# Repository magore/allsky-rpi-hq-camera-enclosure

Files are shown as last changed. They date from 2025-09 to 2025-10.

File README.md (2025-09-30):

# allsky-rpi-hq-camera-enclosure

## Copyright
[MIT License Copyright 2020-2025 Mike Gore]( Copyright.md )

## AllSky enclosure for Raspberry Pi and HQ Camera 
* Includes CAD models in Fusion 360<br>

* Supports Raspberry Pi 4 and 5 Models<br>

* Supports optional Ethernet with POE hats<br>

* Includes BME280 Weather Sensor with Temperature, Humidity and Air Pressure<br>
  + I hacked in the display of Weather sensor information. I just need to convert the code to the new module format and will share that once done.

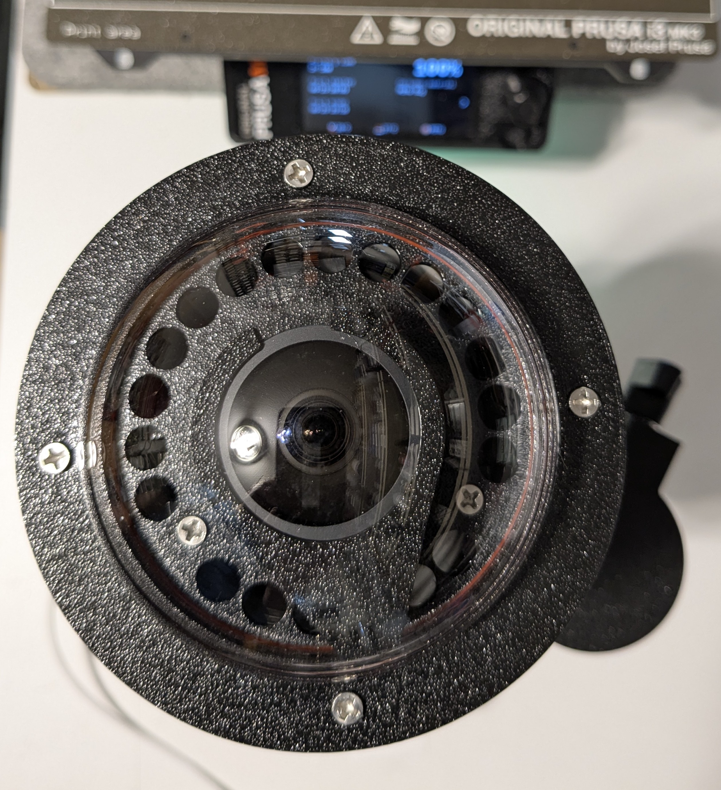
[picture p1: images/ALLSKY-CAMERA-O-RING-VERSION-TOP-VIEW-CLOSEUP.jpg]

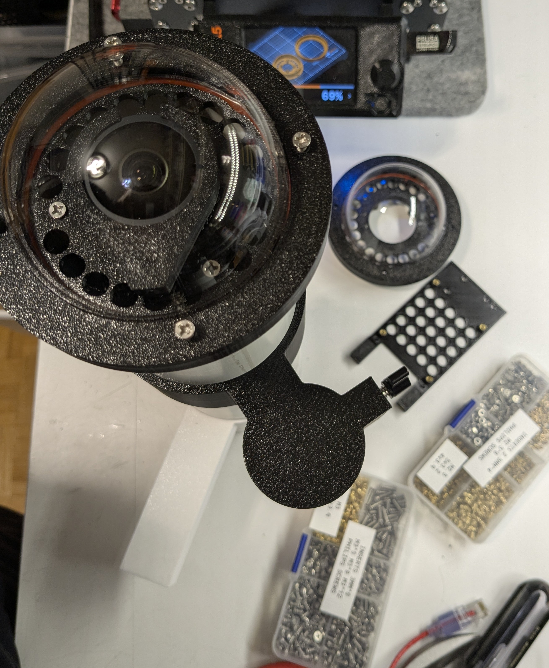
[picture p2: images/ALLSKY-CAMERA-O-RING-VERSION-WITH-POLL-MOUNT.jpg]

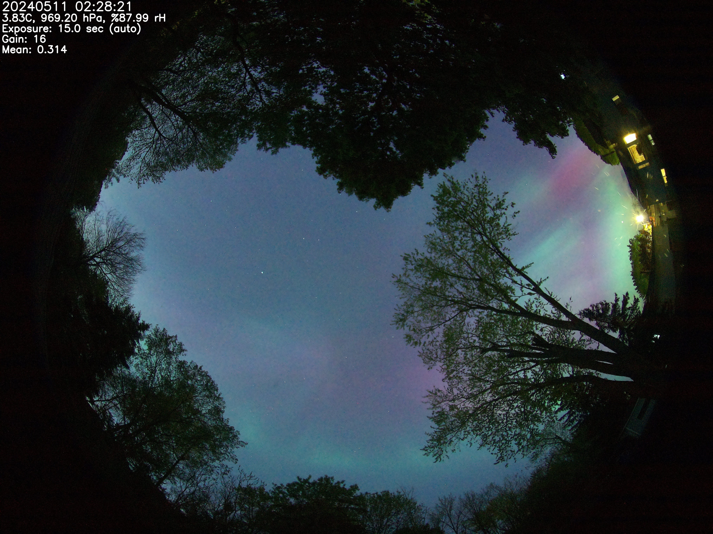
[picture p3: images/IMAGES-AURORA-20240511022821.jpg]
2024 Aurora Image

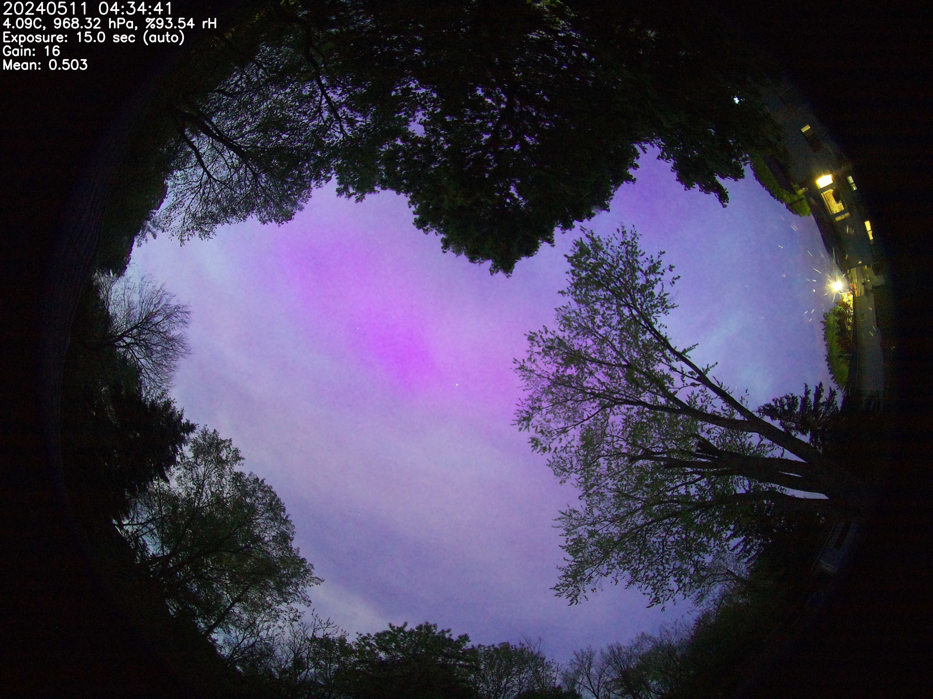
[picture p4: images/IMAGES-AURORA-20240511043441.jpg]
2024 Aurora Image

## Backround of this project
  * I started the ALLSKY Camera Enclosure project back in 2020 and have been using versions of it for the past several years
  * I created CAD models using Fusion 360 
  * I am now at the point where I feel comfortable with the design so I am completing documention presently

## Software requirement
https://github.com/AllskyTeam/allsky - this runs on the Raspberry PI<br>

## Hardware 

[Hardware Requirements]( HARDWARE.md )

[Assembly Instructions and Pictures]( ASSEMBLY.md )

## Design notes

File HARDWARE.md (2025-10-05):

## Hardware requirements
* Not all hardware listed is used - it depends on the Raspberry Pi version 4 or 5 and POE Hat used
* I used kits of stainless steel screws, brass hex spacers and JST connectors so specific part numbers for those items are not included. You can find them on Amazon

### Container, Cover and Weatherproofing
| Description | Source 1 | Source 2|
|---|---|---|
| 3.15inch/80mm w/ 4 Holes Clear Acrylic Flange Plastic | [LINK]( https://www.amazon.ca/dp/B07L6FBMXF ) | [LINK]( https://www.amazon.com/dp/B07L6FBMXF ) |
| IPEX Ecolotube 3 inch PVC Sewer Solid Sewer Pipe 76.2mm ID 82.5mm OD | SKU # 1000659635  [LINK]( https://www.homedepot.ca/product/ipex-ecolotube-3-inch-x-10-feet-pvc-sewer-solid-sewer-pipe/1000659635 ) | |
| 5 Gram Orange Indicatining Silica Packets | [LINK]( https://www.amazon.ca/dp/B07FSZVZFV ) | [ LINK]( https://www.amazon.ca/dp/B07FSZVZFV ) |
| PG7 Cable Gland  with gasket | | |
| Fusion Grip Tape - Silicone | [LINK]( https://www.amazon.ca/dp/B072QYQN7B ) | [LINK]( https://www.amazon.ca/dp/B072QYQN7B ) |
| Silicone O-Ring 82mm OD 76mm ID 3mm Width | [LINK]( https://www.amazon.ca/dp/B0DHRV93PH ) | [LINK]( https://www.amazon.com/dp/B0DHRV93PH ) |
| Silicone O-Ring 88mm OD 82mm ID 3mm Width | [LINK]( https://www.amazon.ca/dp/B0DHRRVRNT ) | [LINK]( https://www.amazon.ca/dp/B0DHRRVRNT) |
| Ethernet LAN Cable Coupler Outdoor Adapter Weatherproof Connection (6-Pack ) | [LINK]( https://www.amazon.ca/dp/B08GPB8M6B ) | [LINK]( https://www.amazon.com/dp/B08GPB8M6B ) |

### Camera and Lens Hardware
| Description | Source 1 | Source 2|
|---|---|---|
| Raspberry Pi HQ Camera Sony IMX477 | Digikey  2648-SC1220-ND | [LINK]( https://www.raspberrypi.com/products/raspberry-pi-high-quality-camera/ ) | 
| CS-MOUNT TO S-MOUNT ADAPTER | Digikey 2938-2000035953-ND | Basler Inc.  2000035953 |
| LOCK RING M12X0.5| Digikey 2938-2000035198-ND | Basler Inc. 2000035198 |
| 12MP 1.85MM ULTRA WIDE ANGEL | Digikey 4555-ED-LENS-M12-170185-12-ND | EDATEC ED-LENS-M12-170185-12 |

### Environmental Sensor and Cables
| Description | Source 1 | Source 2|
|---|---|---|
| QWIIC BME280 ATMOSPHERIC SENSOR | DigiKey 1568-15440-ND | SparkFun 15440 |
| Sparkfun Qwiic Multiport BOB-18012 | Digikey 1568-18012-ND | Sparkfun BOB-18012 | 
| SparkFun Qwiic Cable BOB-18012 | 1568-15081-ND | Sparkfun BOB-18012 | 
| SCREEN Cover - using Faucet Aerator Parts 15/16" | [LINK]( https://www.amazon.ca/dp/B08XNRCDV6 ) | [LINK]( https://www.amazon.com/dp/B08XNRCDV6 ) |

### Misc Connectors
| Description | Source 1 | Source 2|
|---|---|---|
| 2 x 20 (40 Pin) Extra Tall Female 0.1 Inch Pitch Stacking Header | [LINK]( https://www.amazon.ca/Female-Stacking-Header-Compatible-Raspberry/dp/B084Q4W1PW ) | [LINK]( https://www.amazon.com/Female-Stacking-Header-Compatible-Raspberry/dp/B084Q4W1PW ) |
| JST SM female connector Kit | [LINK]( https://www.amazon.ca/dp/B07BGV7H7V ) | [LINK]( https://www.amazon.com/dp/B07BGV7H7V ) |
| ( OPTIONAL ) Micro Molex Crimper: Compatible with D-Sub, JST, JAE Connectors, 32-20AWG | [LINK]( https://www.amazon.ca/dp/B082X45D7T ) | [LINK]( https://www.amazon.ca/dp/B082X45D7T ) |

### Focusing
| Description | Source 1 | Source 2|
|---|---|---|
| 5x10 mm cylinder Neodymium Magnet for focus pointer | [LINK]( https://www.amazon.ca/dp/B0DQKTHBCN ) | [LINK]( https://www.amazon.com/dp/B0DQKTHBCN ) |
| 12x12 mm cylinder Neodymium Magnet external focus magnet | [LINK]( https://www.amazon.ca/dp/B07BS5N22P ) | [LINK]( https://www.amazon.ca/dp/B07BS5N22P ) |

### Cooling
| Description | Source 1 | Source 2|
|---|---|---|
| Noctua NF-A4x10 5V 40x10mm PREMIUM FAN | [LINK]( https://noctua.at/en/products/fan/nf-a4x10-5v ) | |

### POE Networking
| Description | Source 1 | Source 2|
|---|---|---|
| Goalake Poe Managed 5 Port Gigabit Switch | [LINK]( https://www.amazon.ca/dp/B0D2X4M1R7 ) | [LINK]( https://www.amazon.com/dp/B0D2X4M1R7 ) |

### Raspberry PI 4 Specific

#### Raspberry PI 4 Camera
| Description | Source 1 | Source 2|
|---|---|---|
| Raspberry Pi 4 Camera Cable 200mm | | |

#### Raspberry Pi 4 POE
| Description | Source 1 | Source 2|
|---|---|---|
| Waveshare Raspberry Pi 4 POE HAT (E) | [LINK]( https://www.amazon.ca/dp/B0BKK6FXRJ ) | [LINK]( https://www.amazon.com/dp/B0BKK6FXRJ ) |

### Raspberry PI 5 Specific

#### Raspberry PI 5 Camera 
| Description | Source 1 | Source 2|
|---|---|---|
| Raspberry Pi 5 Shielded Camera Cable 200mm | [LINK]( https://www.raspberrypi.com/products/camera-cable/ ) | |

#### Raspberry PI 5 POE HAT OPTIONS
| Description | Source 1 | Source 2|
| Hacker Gadgets Raspberry Pi 5 POE+ Nvme Hat | [LINK]( https://hackergadgets.com/products/nvme-and-poe-hat-for-raspberry-pi-5 ) | |
| (untested ) Waveshare PCIe To M.2 Adapter With PoE Function (C ) For Raspberry Pi 5, Supports NVM | [LINK]( https://www.waveshare.com/poe-m.2-hat-plus-c.htm ) | |

#### Raspberry PI 5 NVME SSD
| Description | Source 1 | Source 2|
|---|---|---|
| Raspberry Pi 5 CORSAIR MP600 MINI 1TB M.2 NVMe PCIe x4 Gen4 2 SSD 2230 | [LINK]( https://www.amazon.ca/dp/B0D9MJCFNK ) | [LINK]( https://www.amazon.com/dp/B0D9MJCFNK ) |

### Screws and Inserts

| Description | Source 1 | Source 2|
|---|---|---|
| 1/4"-20 x 1 Black Thread Thumb Screw, Stainless Steel | [LINK]( https://www.amazon.ca/dp/B0DC5Y3KLQ ) | [LINK]( https://www.amazon.com/dp/B0DC5Y3KLQ ) |
| CNC Kitchen Heatset Inserts M3 H=5.7mm, W=4.6mm, 3.9mm sholder | [LINK]( https://cnckitchen.store/products/heat-set-insert-m3-x-5-7-100-pieces ) | |
| uxcell Knurled Insert Nuts Heatset Inserts M2.5 H=5mm, Wx4mm, 3.25mm sholder | [LINK]( https://www.amazon.ca/dp/B0CTCS2HLT ) | [LINK]( https://www.amazon.ca/dp/B0CTCS2HLT ) ] |
| M3 x 12 Phillips Flat Head Stainless Machine Screw | | |
| M3 x 20 Phillips Flat Head Stainless Machine Screw | | |
| M2.5 x 6 Phillips Flat Head stainless Machine Screw | | |
| M4 x 20 Philips Pan Head Stainless Machine Screw | | |
| M4 Nuts Stainless Machine Screw | | |
| M4 Nuts Stainless Washers | | |
| M2.5 x 6 Brass Standoffs Female-Female | | |
| M2.5 x 15 Brass Standoffs Female-Female | | |

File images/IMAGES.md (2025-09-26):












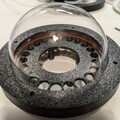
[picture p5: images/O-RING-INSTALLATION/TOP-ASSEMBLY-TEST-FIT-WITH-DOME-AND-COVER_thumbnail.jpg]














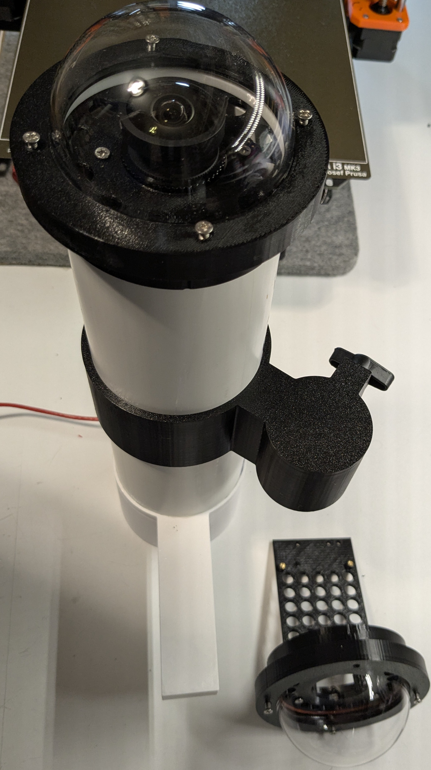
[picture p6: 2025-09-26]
images/OPTICAL-DONE-GASKET-VERSION/ALLSKY-CAMERA-WITH-GASKET-COVER-VERSION.jpg

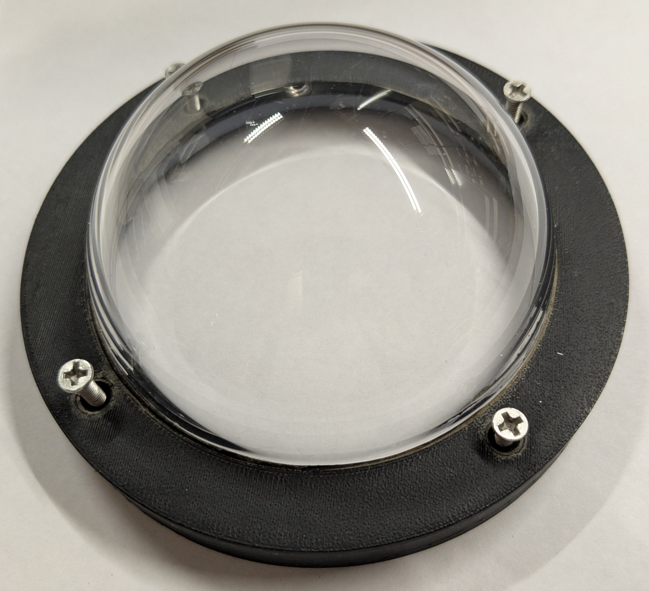
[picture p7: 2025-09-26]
images/OPTICAL-DONE-GASKET-VERSION/OPTICAL-DOME-COVER-GASKET-VERSION.jpg

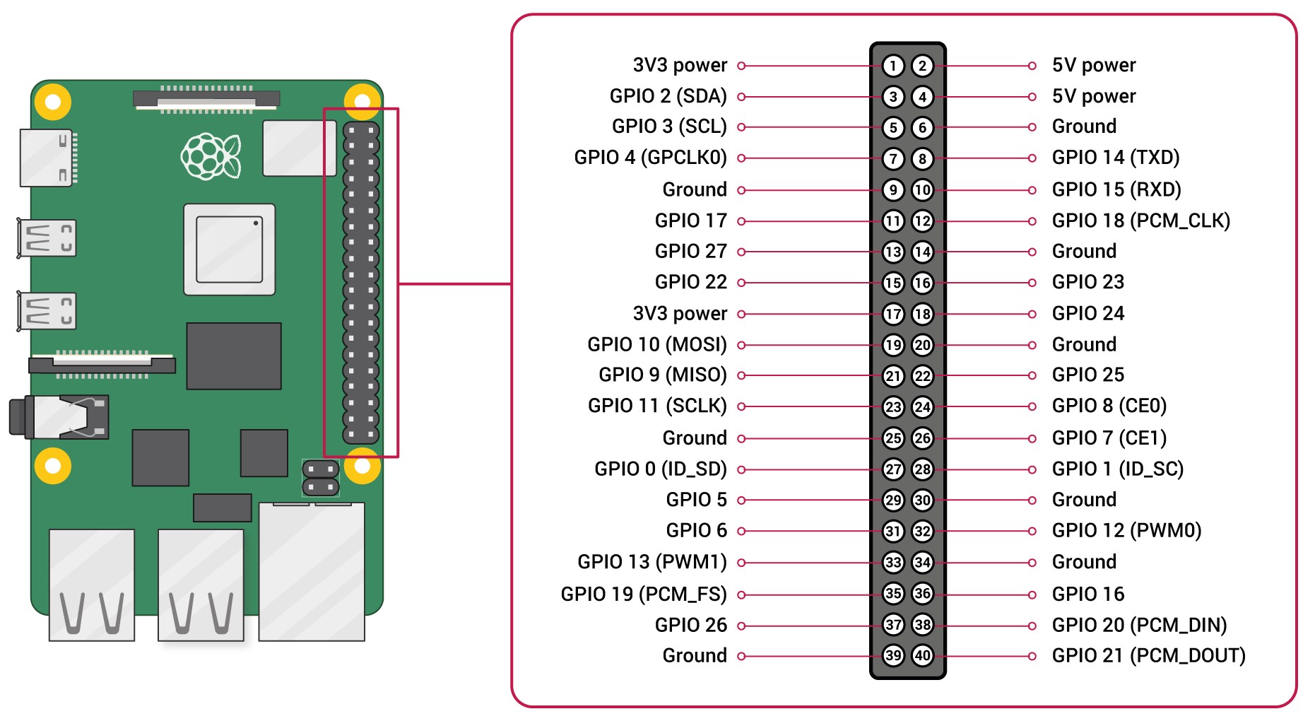
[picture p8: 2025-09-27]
images/RPI-INSTALLATION/RPI-GPIO-PINOUT.jpg

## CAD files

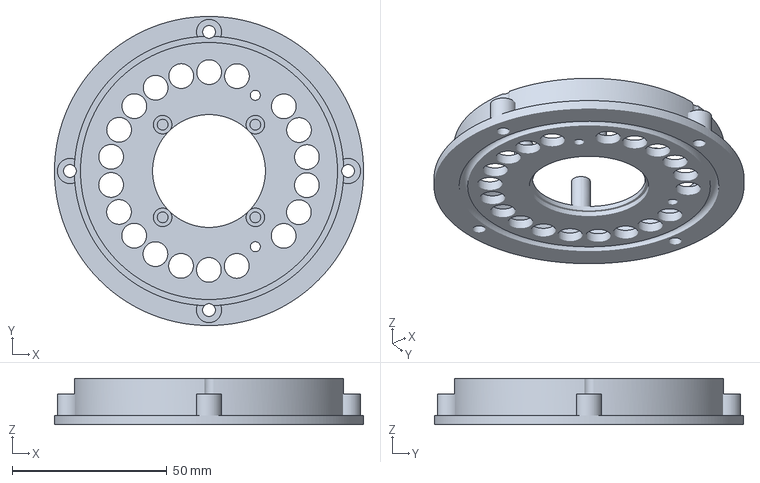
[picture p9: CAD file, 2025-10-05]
CAD/cap-main-o-ring.3mf
100.0 x 100.0 x 15.0 mm

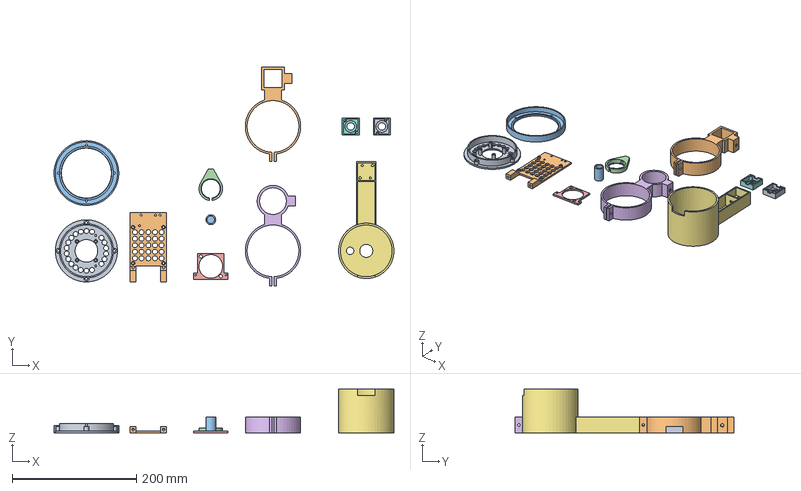
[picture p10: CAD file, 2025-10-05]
CAD/CAP-ORING v27.step
546.7 x 351.6 x 70.0 mm
cap-main-o-ring
cap-rpi-support
cap-dome-holder-o-ring
cap-focus-pointer
cap-fan-holder
cap-poll-holder
cap-weather-sheild
cap-weather-shield-cover-sparkfun-bme280
cap-weather-shield-cover-adafruit-bme680
cap-poll-holder-28x28-poll-2
cap-magnet-holder

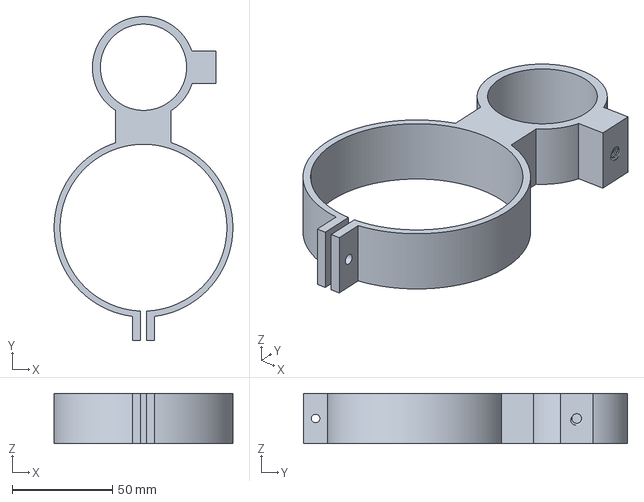
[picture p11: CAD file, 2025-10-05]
CAD/cap-poll-holder.3mf
89.1 x 161.6 x 25.0 mm

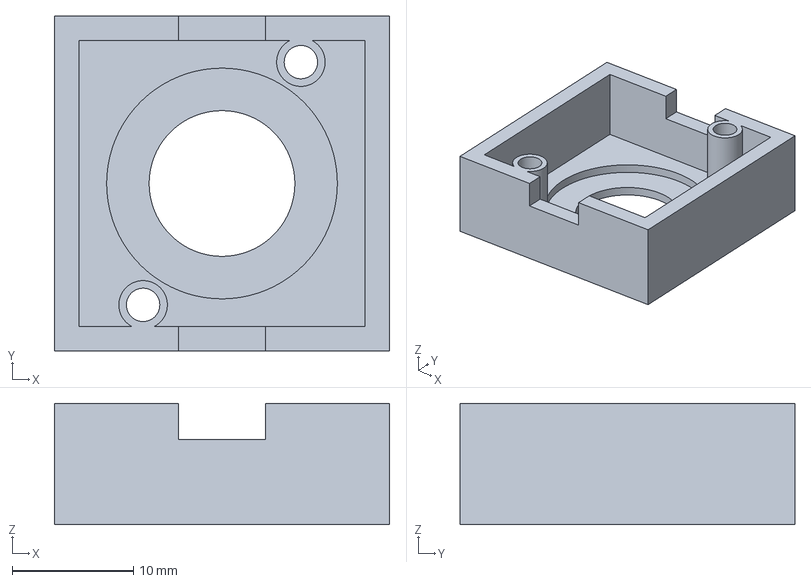
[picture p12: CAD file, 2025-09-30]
CAD/cap-weather-shield-cover-adafruit-bme680.3mf
27.6 x 27.6 x 10.0 mm

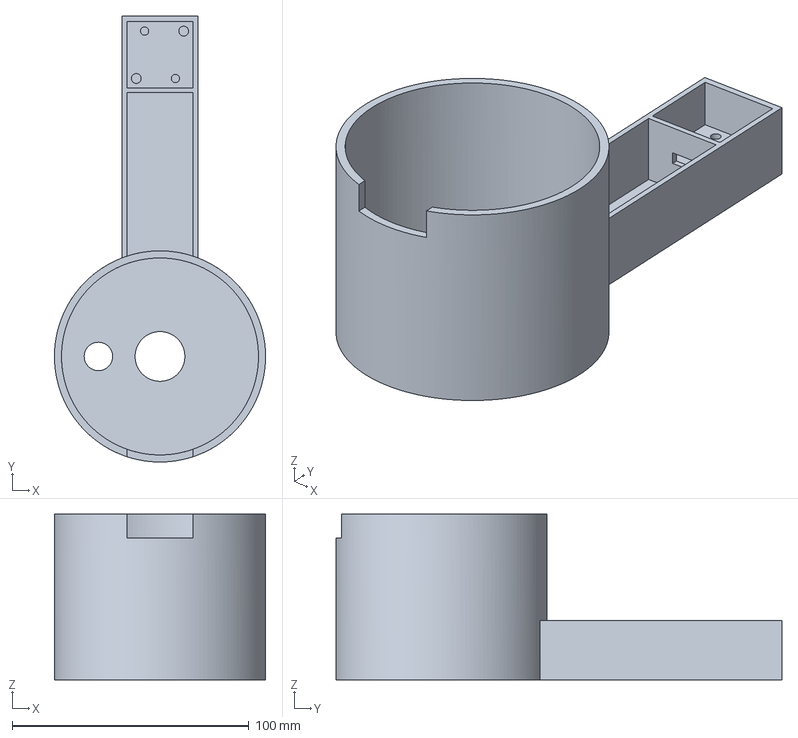
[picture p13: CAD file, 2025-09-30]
CAD/cap-weather-sheild.3mf
89.2 x 188.3 x 70.0 mm

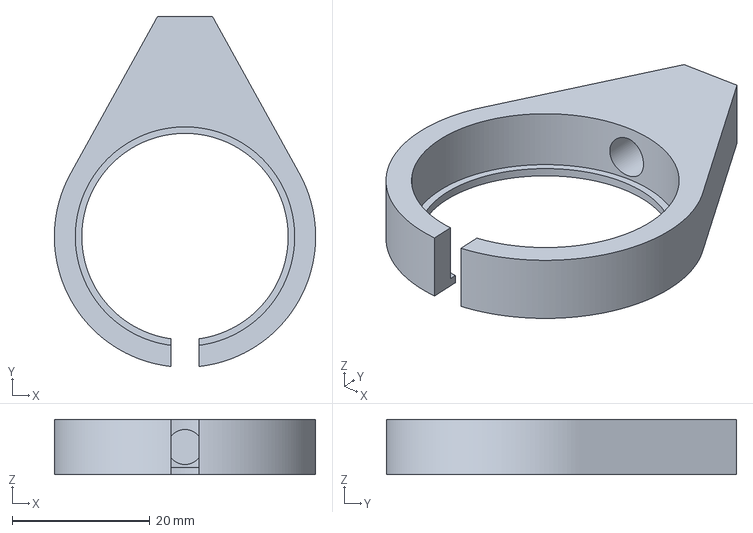
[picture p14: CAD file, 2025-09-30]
CAD/cap-focus-pointer.3mf
38.0 x 50.9 x 8.00 mm

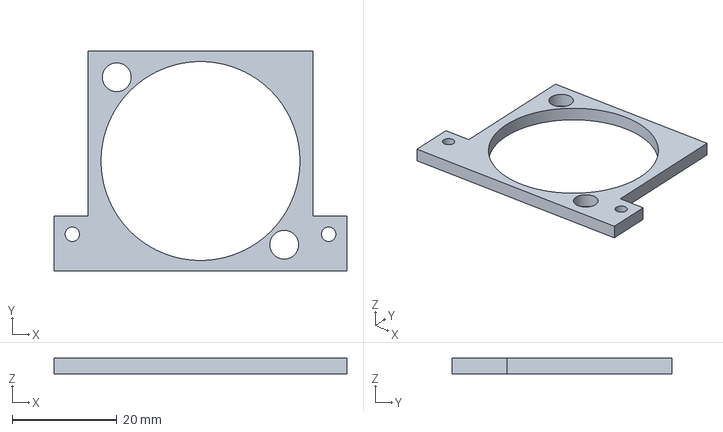
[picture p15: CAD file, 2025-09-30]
CAD/cap-fan-holder.3mf
56.0 x 42.0 x 3.00 mm

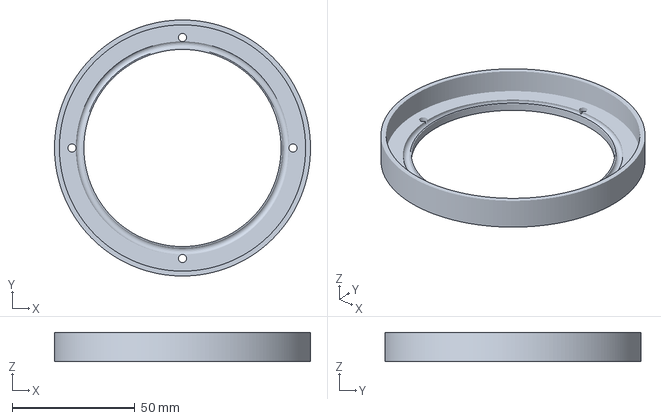
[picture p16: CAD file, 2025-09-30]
CAD/cap-dome-holder-o-ring.3mf
104.2 x 104.2 x 12.0 mm

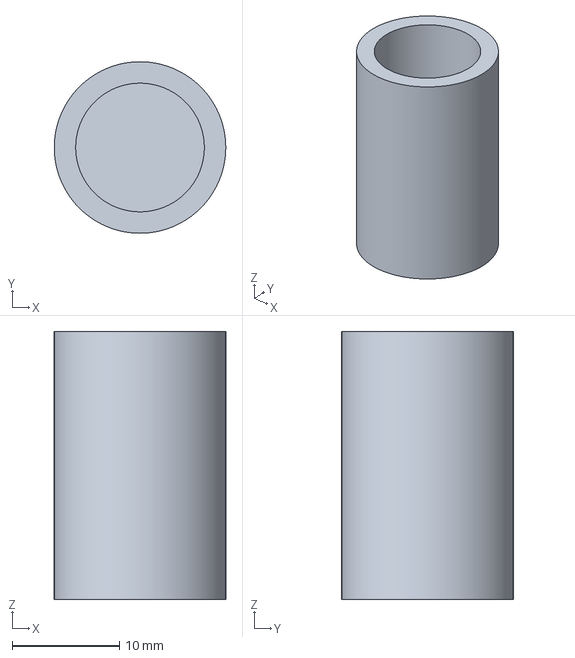
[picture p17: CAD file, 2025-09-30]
CAD/cap-magnet-holder.3mf
16.0 x 16.0 x 25.0 mm

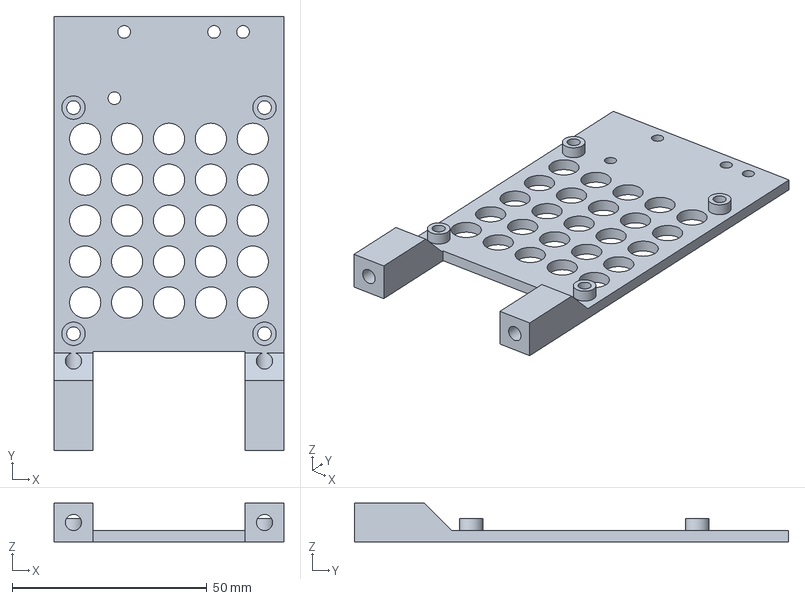
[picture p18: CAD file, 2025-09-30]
CAD/cap-rpi-support.3mf
59.0 x 111.4 x 10.0 mm

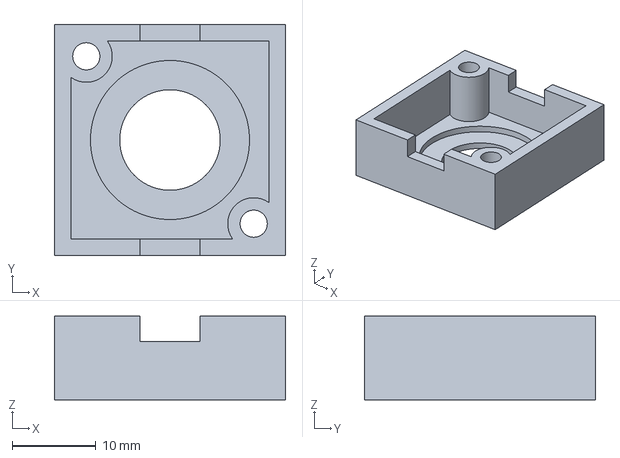
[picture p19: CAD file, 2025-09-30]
CAD/cap-weather-shield-cover-sparkfun-bme280.3mf
27.6 x 27.6 x 10.0 mm

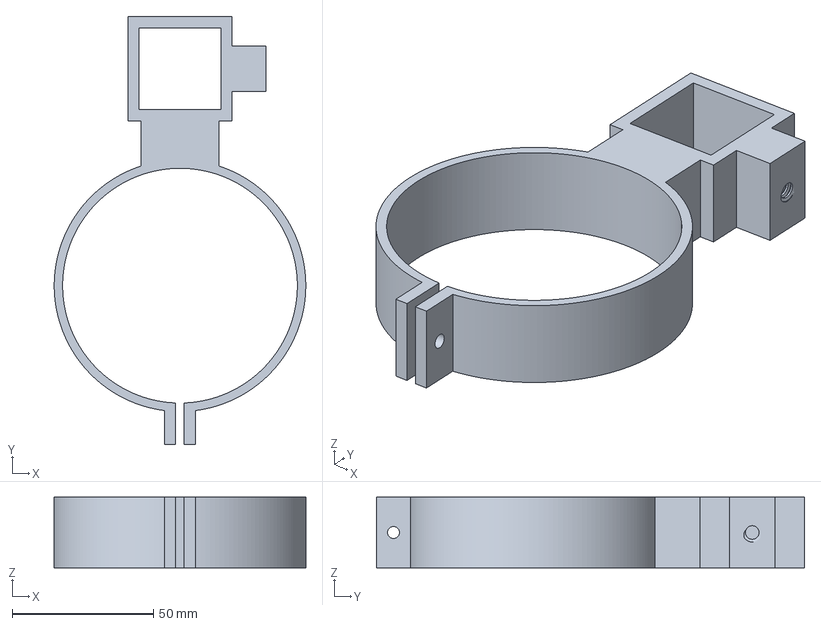
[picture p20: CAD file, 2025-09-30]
CAD/cap-poll-holder-28x28-poll-2.3mf
89.1 x 151.6 x 25.0 mm

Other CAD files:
CAD/CAP-ORING v23.step
CAD/CAP-ORING v24.step
CAD/CAP-ORING v22.step
CAD/CAP-ORING v25.step
CAD/CAP-ORING v22.f3d
CAD/CAP-ORING v23.f3d
CAD/CAP-ORING v24.f3d
CAD/CAP-ORING v25.f3d
CAD/CAP-ORING v27.f3d

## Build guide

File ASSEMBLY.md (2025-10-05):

## Images of Allsky Camera Components - click on each one for larger image
### 3D printing settings
+ I used a PRUSA MK3.5S for printing this project
+ PETG filament 
+ Infill Seittings
  + %100 for TOP Assembly, Cover and CPU support 
  + %20 for all other parts
+ Supports
  + TOP Assembly needs support on build plate enabled for the O-RING grove
+ Colors
  + Black for TOP Assembly, Cover to alow solar heating to help clear ice, fog and snow on the Optical Dome
  + White for everything else to avoid heating of main tube from Sun - The raspberry Pi gets warn enough on its own

### Overview
+ Top view of allsky camera with dome and cover removed
  + 
+ Top view of allsky camera with dome installed
  + 
+ Top view of allsky camera showing dome, cover, poll mount and weather sensor
  + 
+ Bottom view of allsky camera showing PG7 Qwiic connector and weatherproof ethernet connection
  + 
+ Inside view of poll mount
  + Note: this fits on the top of a pipe
  + 

### Older Gasket Version



## Raspberry PI
### Raspberry PI GPIO header Pinouts
+ Credits https://cdn.sparkfun.com/assets/learn_tutorials/1/5/9/5/GPIO.png
  + 
+ Pinout Used for either Raspberry Pi 4 or 5
    | Pin | Function | Pin | Function |
    |---|---|---|---|
    | 1 | 3.3v | 2 | 5V |
    | 3 | SDA | 4 | 5V  FAN Red Wire|
    | 5 | SCL | 6 | GND  FAN Black Wire|
    | 7 | Not Used | 8 | Not Used |
    | 9 | GND | 10 | Not Used |

### Qwiic I2c cable pinouts
+ Used to map cable colors for Qwiic female to JST female adapter cable
    | Pin | Function | Color | Alternate Color |
    |---|---|---|---|
    | 1 | GND | BLACK | |
    | 2 | VCC 3.3V | READ | |
    | 3 | SDA | BLUE | GREEN |
    | 4 | SCL | YELLOW | WHITE |
    
### Raspberry PI Wiring - FAN and QWIIC
  + Raspberry Pi 5 Wiring
    + 
  + Raspberry Pi 4 Wiring
    + 

### Raspberry Pi assembly
+ Raspberry PI 5 assembly stack with the Hacker Gadgets Raspberry Pi 5 POE+ and NVME HAT
  + Note: there is an internal weather sensor to measure temperature and humidity while testing
  + When this sensor is not used you need an female to female Qwiic adapter or multiport adapter to connect the RPI Qwiic connection to the external BME280 sensor
  + Side view
    + 
  + Top View
    + 
  + Raspberry Pi 5 Battery
    + 
  + Raspberry Pi 5 Header Extension
    + 

+ Raspberry Pi 4 assembly stack with POE HAT
  + 
  + 
  + 

### Raspberry Pi 4 Waveshare Poe HAT version E 
+ Waveshare POE HAT (E) https://www.waveshare.com/wiki/PoE_HAT_(E)
  + 
  + Pinout Pin side view components face up
  + Left to Right, Top to Bottom
    | ROW | Col 1 | Col 2 | Col 3 | Col 4 |
    |---|---|---|---|---|
    | Top Row FAN Connections | GND | 5V | 5V | GND |
    | Bottom Row QWIIC I2C Connections | GND | 3.3V | SDA | SCL |
  + 

### Raspberry Pi 5 POE HAT 
+ Hacker Gadgets Raspberry Pi 5 PoE+ and NVME Hat
  + 
  + Must use tall header extension to permit access to GPIO pins
    + This is a 20 x 2 female to male extension header with long male pins
  + See GPIO section above

### O-RING version
+ Remove support material from 3D print using a fine flat screw driver
  + insert vertically into the support gap and gently pry up repeat process every 30 degrees until the support releases
  + 
+ O-Ring instalation
  + The O-Ring grooves have been designed with more then half a circle diemeter 
    + This is means they must be slightly compressed into the opening but will then be held in place
  + Lay O-Ring on top of O-Ring slot on print
	+ To avoid over stretching O-Ring press the O-Ring straight down into slot at two oppose sides at the same time
      + Work 180 degrees apart, then 90, the 45, etc, until the O-Ring is fully inserted
  + O-Rings used for top assembly
    + Note: This O-Ring will be stretched a small amount when inserted
      + This was done to move the center line of this O-Ring silightly more into the dome flang area
    + 
  + O-Ring installed in top assembly
    + 
  + O-Rings used for top cover
    + 
  + O-Ring installed in top cover
    + 
  + O-Rings top cover and optical dome parts
    + 
  + O-Rings top cover and optical dome fitted
    + 
  + Dome, Top Cover and main assembly test fit
    + 
### Heatset Inserts
+ Heatset Inserts for this project
  + These inserts fit the designed holes for the project
    + CNC Kitchen M3 H=5.7mm, W=4.6mm, Insert sholder = 3.9mm
      + 
    + UXCELL M2.5 H=5mm, W=4mm, Insert sholder = 3.25mm 
      + https://www.amazon.ca/dp/B0CTCS2HLT
	  + https://www.amazon.ca/dp/B0CTCS2HLT

+ Using a soldering iron to heatset - melt inserts into project holes
  + 
    + I just use the default soldering temperature of 350C for doing this
    + Make sure you throughly clean soldering oron tip
    + Suggest using a wet paper towel when the iron is hot - the steam will help with cleaning
    + Make sure you keep the soldering iron vertical 
    + Let insert melt into part untill just below surface
    + 

#### Heatset insert locations
+ M3 x 5.7 inserts are used for holding CPU support onto top assembly with M3 x 12mm flat head tapered philips screws
+ M2.5 x 4 inserts are used for holding camera circuit board onto top assembly and RPI onto CPU support 
  + 
  + 
  + 
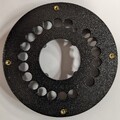
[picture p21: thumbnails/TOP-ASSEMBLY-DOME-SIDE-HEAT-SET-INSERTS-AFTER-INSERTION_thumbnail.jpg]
  + 
  + 
  + 

### Weather Sensor
  + Sparkfun BME280 wearther sensor installation
    + Uses M3 x 5.7 heat set inserts - note the are other M2.5 insert holes for another sensor you can ignore
    + 
  + Glue 15/16" faucet screen into inside of top cover with hot-glue
  + Secure cover with M3 x 15 philip panhead screws
    + 

### Weatherproof Gaskets
+ Secure PG7 and RJ45 feedtrough to bottom cover and weather sheild holder
  + The RJ45 has a cover for the inside and outside
  + I am using a 2ft ultrathin cat 5e ethernet cable
    + The weather glad that goes over the jack seals on the headshell of the RJ45 and seals fully
  + The PG7 is used to pass the 500mm Qwiic cable to the weather sensor
    + I rapped some self sealling fusion selicone tape around the Qwiic cable to ensure a seal with the PG7 cable gland
  + 

### Magnetic Focus Adjustment
  + This permits moving the focus point using a strong external magnet 
  + 

### Image Examples



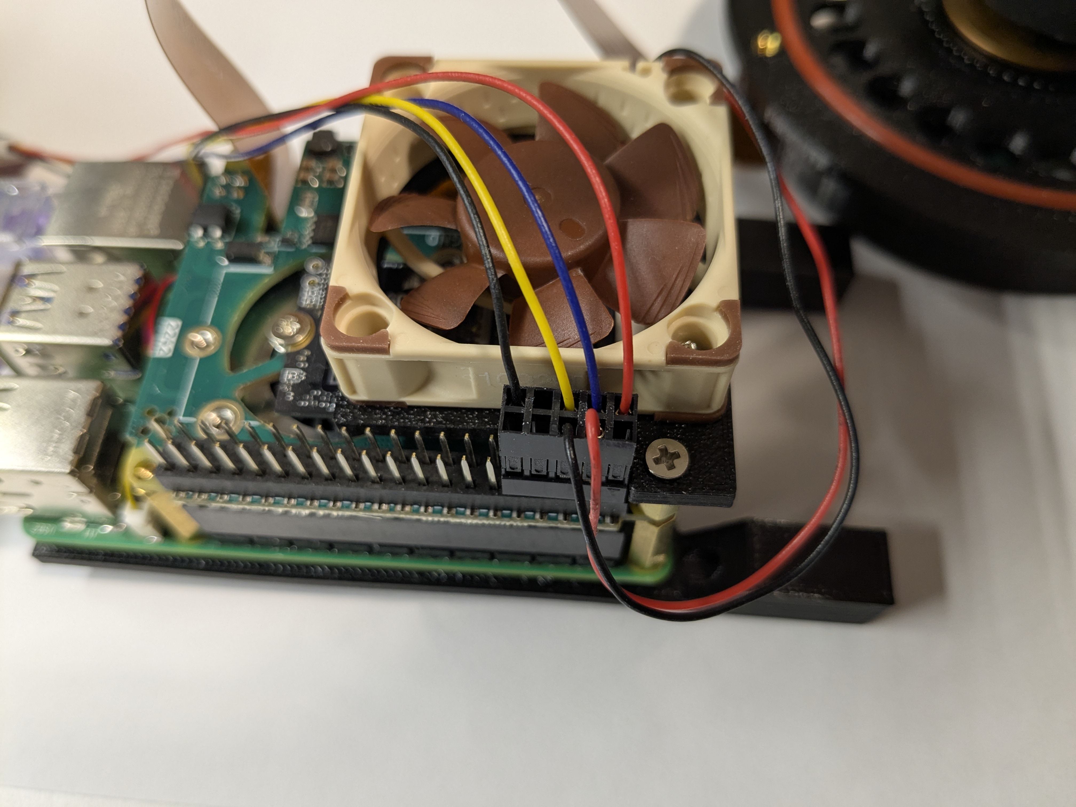
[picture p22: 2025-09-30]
images/RPI-INSTALLATION/SIDE-VIEW-OF-RASPBERRY-PI-5-WIRING-CLOSEUP.jpg

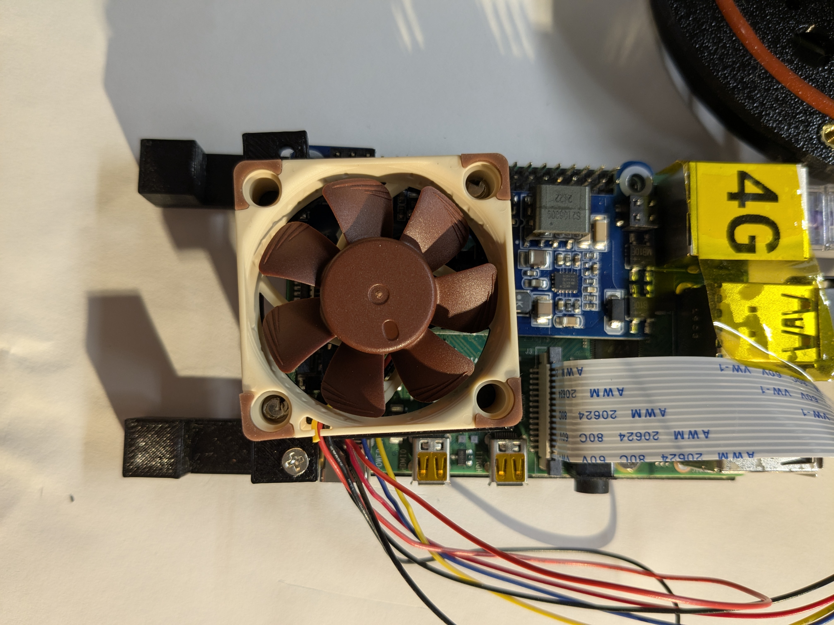
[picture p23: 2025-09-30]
images/RPI-INSTALLATION/TOP-VIEW-OF-RASPBERRY-PI-4-WITH-FAN.jpg

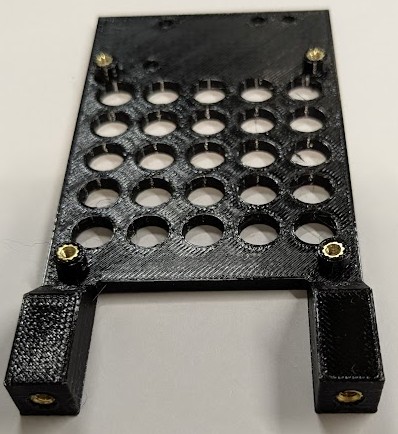
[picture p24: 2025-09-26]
images/HEAT-SET-INSERT-INSTALLATION/TOP-ASSEMBLY-RPI-SUPPORT-HEAT-SET-INSERTS-INSTALLED.jpg

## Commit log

2023-10-30 Initial checkin of CAD files
    [CAPV5 v1.f3d, CAPV5 v1.step, cap-base-holder.3mf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]
2023-10-30 Added picture of enclosure
2025-08-15 Release update
    [CAPV5 v15.f3d, CAPV5 v15.step, CAPV5 v16.f3d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]
2025-09-12 Updated weather sheild to function as pipe cap. Modified sendor routing. Updated Raspberry Pi holder adding more holes for cooling
    [CAPV5 v28.f3d, CAPV5 v28.step, CAPV5 v29.f3d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]
2025-09-13 Added link to https://github.com/AllskyTeam/allsky for software that can run on the Raspberry PI
2025-09-13 Added note about the CAD models being Fusion 360
2025-09-24 Added O-RING design for sealing dome
    [CAP-ORING v29.f3d, CAP-ORING v29.step, CAP-ORING v30.f3d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]
2025-09-24 Documentation and Photo Updates
    [CAP-ORING v31.f3d, CAP-ORING v31.step]
2025-09-25 Updated Focus pointer - shortened for more clearance
    [CAP-ORING v32.f3d, CAP-ORING v32.step, CAP-ORING v33.f3d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]
2025-09-26 Split up hardware into sections modified O-RING hole dimentions for main cap
    [CAP-ORING v35.f3d, CAP-ORING v35.step, cap-main-o-ring.3mf]
2025-09-27 Added notes for assembly
    [CAP-ORING v36.f3d, CAP-ORING v36.step, cap-main-o-ring.3mf]
2025-09-27 Renamed IMAGES.md to ASSEMBLY.md
2025-09-27 Updated ASSEMBLY
2025-09-30 Major updates to CAD drawing - updated all object 3MF and GCODE files Now using parameters in CAD drawing for all heatset inserts, screw holes, body pipe dimension, thickness, etc Reprinted and teste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
    [CAP-ORING v22.f3d, CAP-ORING v22.step, CAP-ORING v23.f3d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]
2025-10-01 Updated M2.5 heatset insert supplier to uxcell
2025-10-01 Updated M2.5 heatset inserts supplier to uxcell
2025-10-01 Changed M2.5 heatset insert to uxcell
2025-10-05 Modified Poll Holder - removed pipe cover so holder can be moved down a pipe if needed
    Modified that Main Cap Assempy adding a recessed with 2mm more space for the camera C-Mount focus ring - up from original 0.5mm
    Originally the 0.5mm clearance was constarined by camera boards placement of mounting holes thus limiting the diameter of the support posts for the heatset inserts
    The recessed area is on the opposite side of the board so doesn't impact the support posts diameter. Added a separate schematic for this to make changes easier.
    Updated the CAD 3MF files for the following files
    CAD/cap-main-o-ring.3mf
    CAD/cap-poll-holder.3mf
    Created new GCODE files for
    CAD/cap-main-o-ring_0.4n_0.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
    [CAP-ORING v27.f3d, CAP-ORING v27.step, cap-main-o-ring.3mf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]
